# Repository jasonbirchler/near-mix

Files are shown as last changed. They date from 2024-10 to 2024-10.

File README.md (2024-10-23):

# A Near Mix

**Common Denominator Devices 'A Near Mix' Eurorack Module.**

6 input, 2 output minimal panning mixer in 12hp.
Designed for Intellijel 1U format.

A Near Mix is an SMD variant of [Mixor Image][mixor-git], which is built upon the bones of Nearness designed by [Jesper Särnesjö][nearness-git].
Nearness is a product of the *[llllllll][nearness-lines]* community. 

# Changes

* Inputs have been rearranged. Proximity to output now implies strength of panning.
* This module has been re-designed to suit the Intellijel 1U format behind a 12hp panel.
* Resistor values have been changed throughout to give a different stereo image *(An automated method was used for this to select nearest common resistor values based on angle of placement in the stereo field for each input)*
* An additional centre input with a high pass filter has been added so as not to muddy the middle of the stereo field
* Stereo in & out *link* connectors have been added allowing for chaining of multiple modules or linking to other manufacturers' stereo modules without patch cables

# PCB & Panel

KiCad files are provided for the 2 PCB's and a plain panel without artwork.

Gerber files can be found in the Gerbers directory.

# License

In accordance with the wishes of the designer of the work that inspired this, and in the spirit of community development, this work is licensed under a
[Creative Commons Attribution-ShareAlike 4.0 International License][cc-by-sa].

[][cc-by-sa]

[][cc-by-sa]

[nearness-lines]: https://llllllll.co/t/prototyping-nearness-a-minimal-panning-mixer-module/8330
[mixor-git]: https://github.com/modular-maculata/mixor-image
[nearness-git]: https://github.com/sarnesjo/nearness
[mi-photo]: https://github.com/modular-maculata/mixor-image/blob/main/mixor-image.jpeg
[cc-by-sa]: http://creativecommons.org/licenses/by-sa/4.0/
[cc-by-sa-image]: https://licensebuttons.net/l/by-sa/4.0/88x31.png
[cc-by-sa-shield]: https://img.shields.io/badge/License-CC%20BY--SA%204.0-lightgrey.svg

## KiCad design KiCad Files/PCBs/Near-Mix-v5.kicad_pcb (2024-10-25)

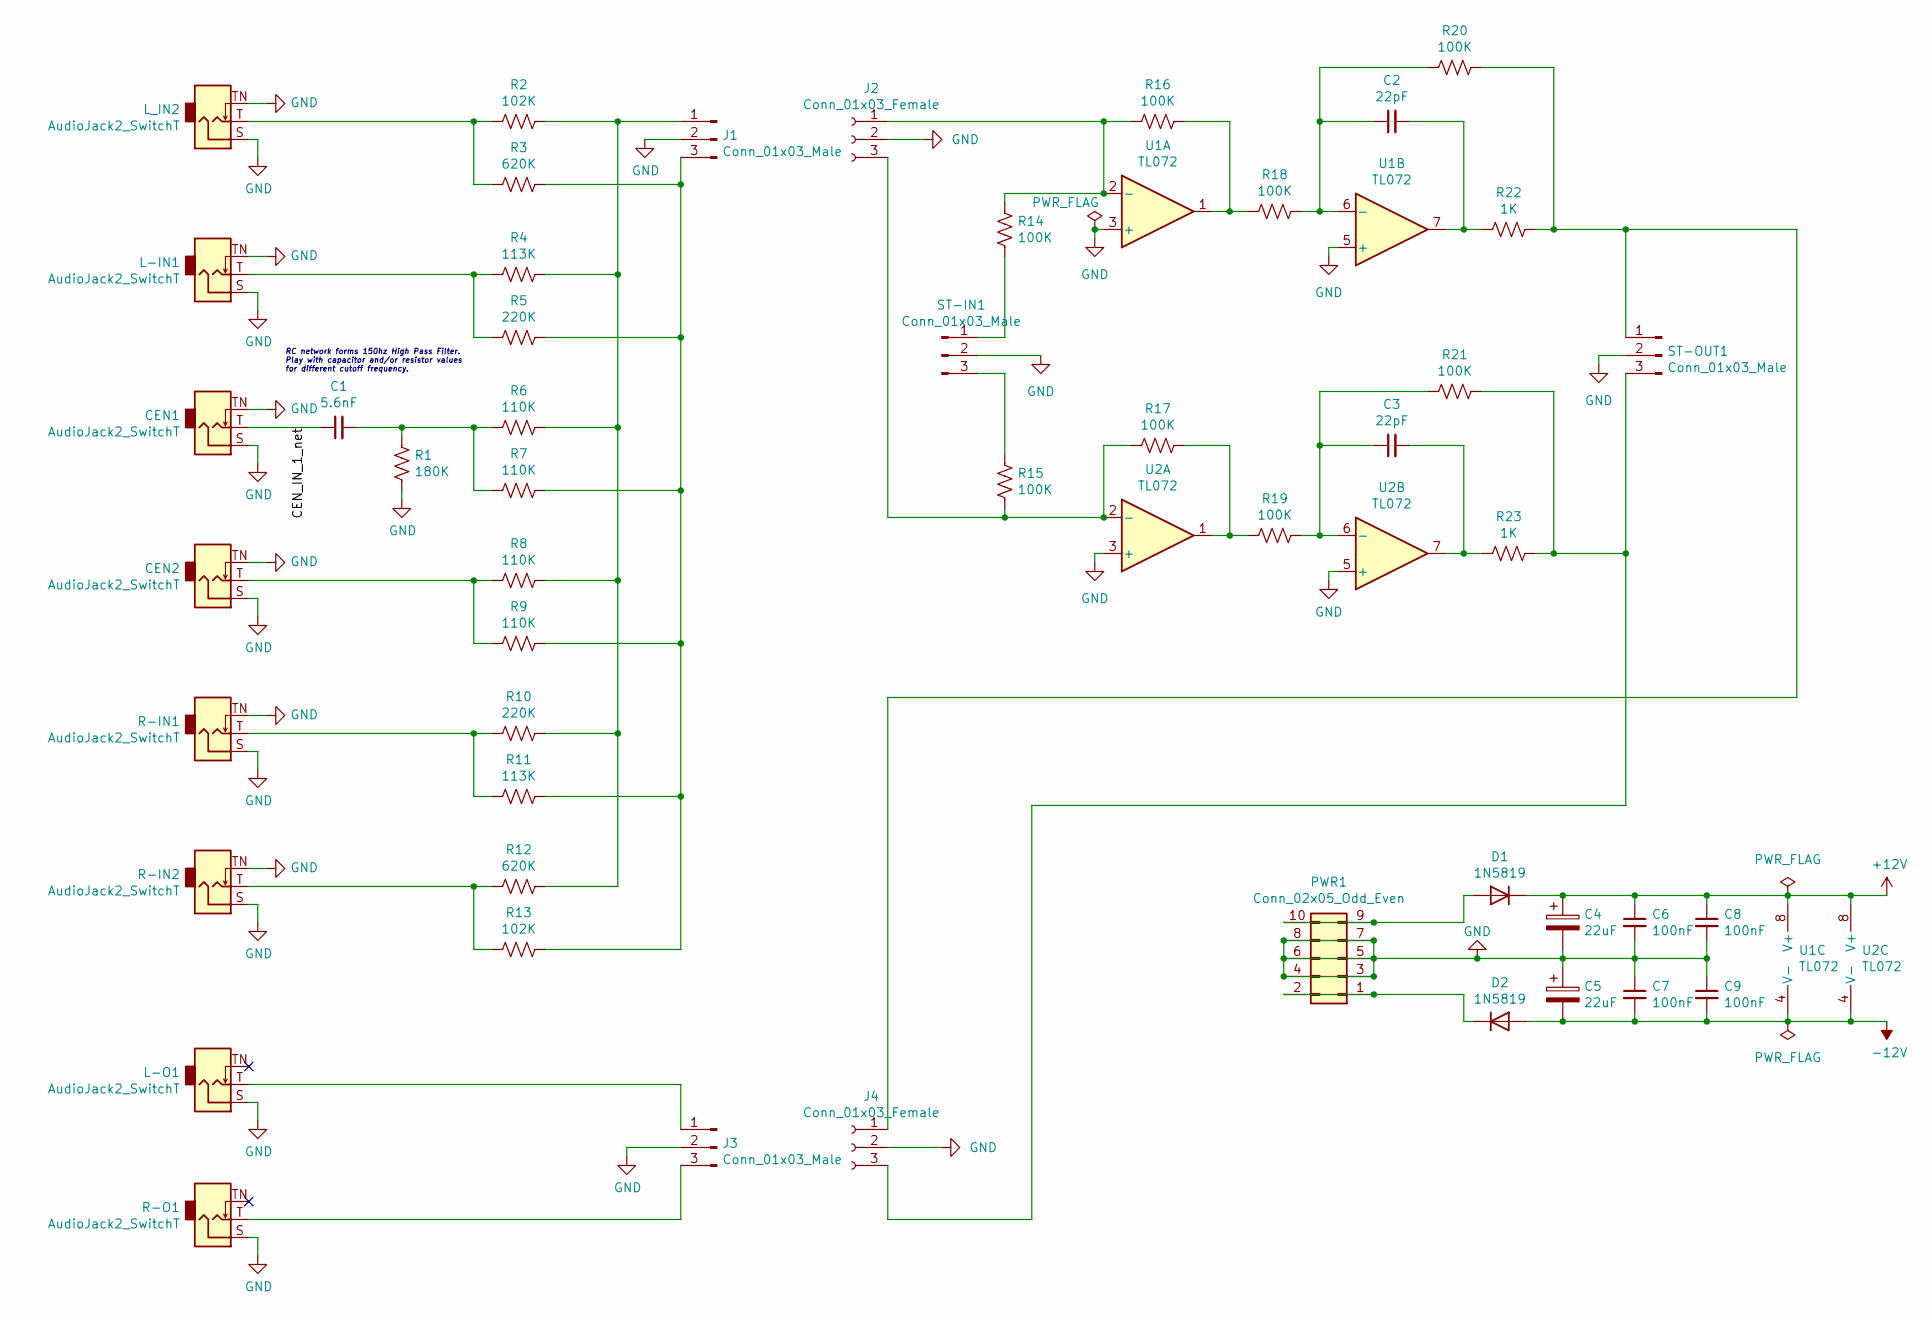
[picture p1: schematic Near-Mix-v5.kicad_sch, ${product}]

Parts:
C1: 5.6nF; C_1206_3216Metric
C2, C3: 22pF; C_1206_3216Metric
C4, C5: 22uF; CP_Elec_3x5.3
C6, C7, C8, C9: 100nF; C_1206_3216Metric
CEN1, CEN2: AudioJack2_SwitchT; Jack_3.5mm_QingPu_WQP-PJ398SM_Vertical
D1, D2: 1N5819; D_SOD-123F
J1, J3: Conn_01x03_Male; PinHeader_1x03_P2.54mm_Vertical
J2, J4: Conn_01x03_Female; PinSocket_1x03_P2.54mm_Vertical
L-IN1: AudioJack2_SwitchT; Jack_3.5mm_QingPu_WQP-PJ398SM_Vertical
L-O1: AudioJack2_SwitchT; Jack_3.5mm_QingPu_WQP-PJ398SM_Vertical
L_IN2: AudioJack2_SwitchT; Jack_3.5mm_QingPu_WQP-PJ398SM_Vertical
PWR1: Conn_02x05_Odd_Even; PinHeader_2x05_P2.54mm_Vertical
R1: 180K; R_1206_3216Metric
R2, R13: 102K; R_1206_3216Metric
R3, R12: 620K; R_1206_3216Metric
R4, R11: 113K; R_1206_3216Metric
R5, R10: 220K; R_1206_3216Metric
R6, R7, R8, R9: 110K; R_1206_3216Metric
R14, R15, R16, R17, R18, R19, R20, R21: 100K; R_1206_3216Metric
R22, R23: 1K; R_1206_3216Metric
R-IN1, R-IN2: AudioJack2_SwitchT; Jack_3.5mm_QingPu_WQP-PJ398SM_Vertical
R-O1: AudioJack2_SwitchT; Jack_3.5mm_QingPu_WQP-PJ398SM_Vertical
ST-IN1: Conn_01x03_Male; FanPinHeader_1x03_P2.54mm_Vertical
ST-OUT1: Conn_01x03_Male; FanPinHeader_1x03_P2.54mm_Vertical
U1, U2: TL072; SOIC-8_3.9x4.9mm_P1.27mm

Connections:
+12V: C4.1, C6.1, C8.1, D1.1 (K), U1.8 (V+), U2.8 (V+)
-12V: C5.2, C7.2, C9.2, D2.2 (A), U1.4 (V-), U2.4 (V-)
/CEN_IN_1_net: C1.1, CEN1.T
GND: C4.2, C5.1, C6.2, C7.1, C8.2, C9.1, CEN1.S, CEN1.TN, CEN2.S, CEN2.TN, J1.2, J2.2, J3.2, J4.2, L-IN1.S, L-IN1.TN, L-O1.S, L_IN2.S, L_IN2.TN, PWR1.3, PWR1.4, PWR1.5, PWR1.6, PWR1.7, PWR1.8, R1.2, R-IN1.S, R-IN1.TN, R-IN2.S, R-IN2.TN, R-O1.S, ST-IN1.2, ST-OUT1.2, U1.3 (+), U1.5 (+), U2.3 (+), U2.5 (+)
unnamed: C1.2, R1.1, R6.1, R7.1
unnamed: C2.2, R22.1, U1.7
unnamed: C3.2, R23.1, U2.7
unnamed: CEN2.T, R8.1, R9.1
unnamed: D1.2 (A), PWR1.9, PWR1.10
unnamed: D2.1 (K), PWR1.1, PWR1.2
unnamed: J1.1, R2.2, R4.2, R6.2, R8.2, R10.2, R12.2
unnamed: J1.3, R3.2, R5.2, R7.2, R9.2, R11.2, R13.2
unnamed: J2.1, R14.1, R16.1, U1.2 (-)
unnamed: J2.3, R15.2, R17.1, U2.2 (-)
unnamed: J3.1, L-O1.T
unnamed: J3.3, R-O1.T
unnamed: J4.1, R20.2, R22.2, ST-OUT1.1
unnamed: J4.3, R21.2, R23.2, ST-OUT1.3
unnamed: L-IN1.T, R4.1, R5.1
unnamed: L_IN2.T, R2.1, R3.1
unnamed: R16.2, R18.1, U1.1
unnamed: R17.2, R19.1, U2.1
unnamed: R10.1, R11.1, R-IN1.T
unnamed: R12.1, R13.1, R-IN2.T
unnamed: R14.2, ST-IN1.1
unnamed: R15.1, ST-IN1.3
unnamed: C2.1, R18.2, R20.1, U1.6 (-)
unnamed: C3.1, R19.2, R21.1, U2.6 (-)

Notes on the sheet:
RC network forms 150hz High Pass Filter. Play with capacitor and/or resistor values for different cutoff frequency.

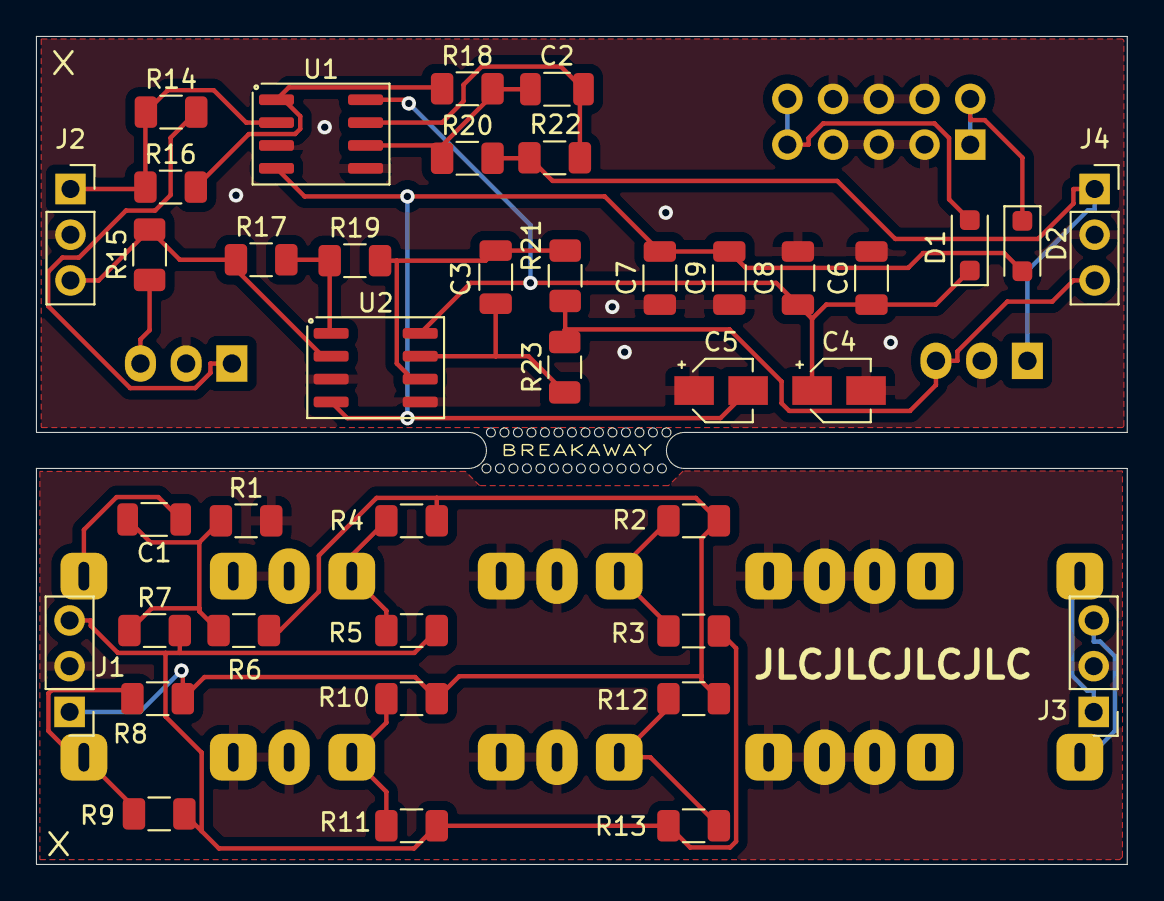
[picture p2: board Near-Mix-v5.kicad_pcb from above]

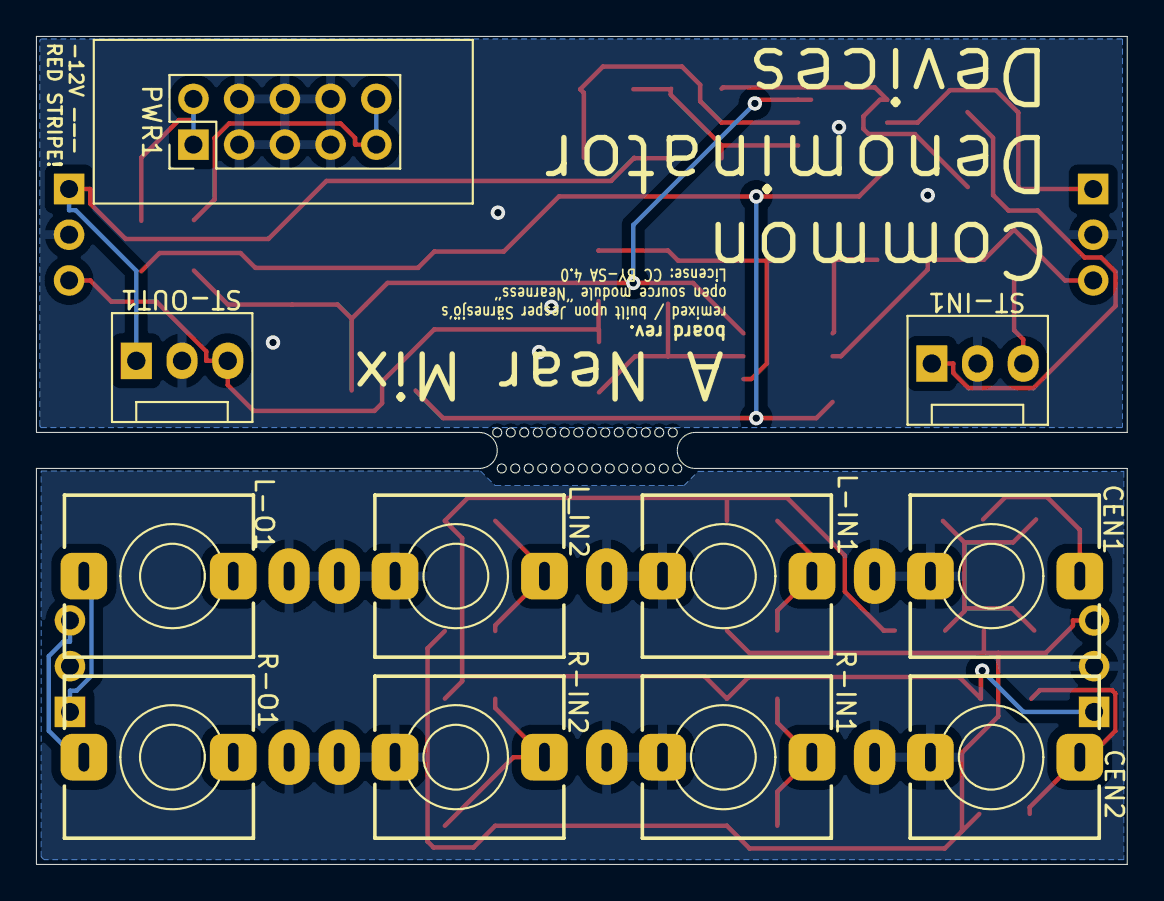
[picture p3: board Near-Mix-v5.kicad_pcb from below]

Board: 2 copper layers, 60.6 x 46.0 mm, 79 parts (11 on the bottom side), 28 nets.

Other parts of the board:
MOUSE_BITE_01, MOUSE_BITE_02, MOUSE_BITE_03, MOUSE_BITE_04, MOUSE_BITE_05, MOUSE_BITE_06, MOUSE_BITE_07, MOUSE_BITE_08, MOUSE_BITE_09, MOUSE_BITE_10, MOUSE_BITE_11, MOUSE_BITE_12, MOUSE_BITE_13, MOUSE_BITE_14, MOUSE_BITE_15, MOUSE_BITE_16, MOUSE_BITE_17, MOUSE_BITE_18, MOUSE_BITE_19, MOUSE_BITE_20, MOUSE_BITE_21, MOUSE_BITE_22, MOUSE_BITE_23, MOUSE_BITE_24, MOUSE_BITE_25, MOUSE_BITE_26, MOUSE_BITE_27, MOUSE_BITE_28: 0.5mm_Hole; MountingHole_0.5mm

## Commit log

2023-11-23 fix all missing symbols and update to KiCad7 project
    [Mixor-Image-v5.kicad_sch]
2023-11-24 remove Modular Maculata branding
    [Mixor-Image-v5.kicad_pcb]
2023-11-28 only 1 error committing before flipping components so all SMD are on the same side
    [Mixor-Image-v5.kicad_pcb, Mixor-Image-v5.kicad_sch]
2024-06-09 fix missing symbols and eeschema errors
    [Mixor-Image-v5.kicad_sch]
2024-06-09 remove Modular Maculata graphics
    [Mixor-Image-v5.kicad_pcb]
2024-06-09 adds C/D logo, change resistors to SMD
    [Mixor-Image-v5.kicad_pcb, Mixor-Image-v5.kicad_sch, bom.csv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]
2024-06-09 removing production directory so that its contents will be ignored
    [bom.csv, designators.csv, positions.csv]
2024-06-09 updated panel with C/D graphics
    [Mixor-Image-v5.kicad_pcb, Mixor_Image-Plain_Panel.kicad_pcb, freerouting.dsn]
2024-06-09 PCB cleanup
    [Mixor-Image-v5.kicad_pcb]
2024-06-09 remove Gerber Files dir
2024-06-09 creates separate directories for PCBs and panel brings panel layout back from the dead
    [Mixor-Image-v5.kicad_pcb, Mixor-Image-v5.kicad_sch, Mixor-Image-v5.sch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]
2024-06-09 version submitted to JLCPCB 2024-06-09
    [Mixor-Image-v5.kicad_pcb, Mixor_Image-Plain_Panel.kicad_pcb, freerouting.dsn]
2024-10-23 rename Kicad files and update schematic info
    [Near-Mix-v5.kicad_pcb, Near-Mix-v5.kicad_sch, Near-Mix-v5.sch]
2024-10-25 first fully SMD version ordered from JLCPCB 2024-10-24
    [Near-Mix-v5.kicad_pcb, Near-Mix-v5.kicad_sch]
2024-10-25 uses different footprint for diodes - JLC didn't have parts to match previous updates labels so they are oriented sanely and not cut off by pads ordered 2024-10-25 order for previous commit cancelled
    [Near-Mix-v5.kicad_pcb, Near-Mix-v5.kicad_sch]

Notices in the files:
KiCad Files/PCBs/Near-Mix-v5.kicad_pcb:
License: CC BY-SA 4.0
